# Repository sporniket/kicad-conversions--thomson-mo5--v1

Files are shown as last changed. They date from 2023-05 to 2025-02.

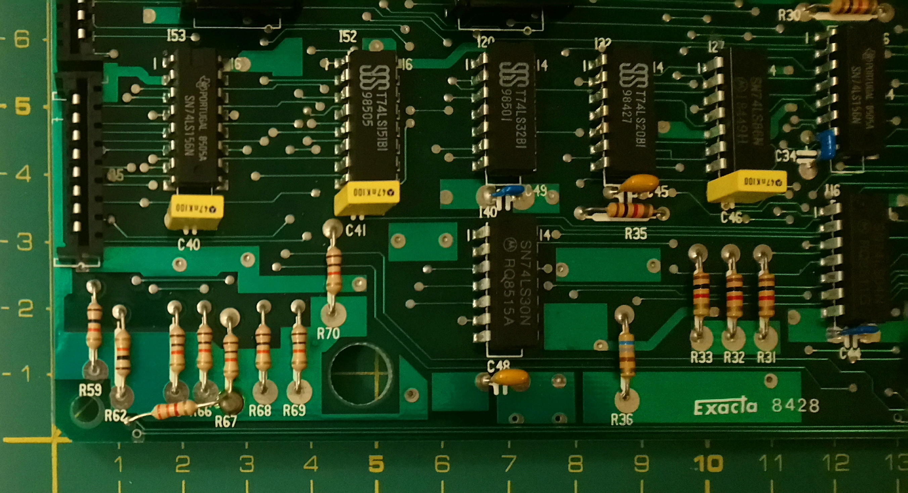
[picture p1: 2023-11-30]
references/motherboard/pictures_top/DSC_1537.JPG

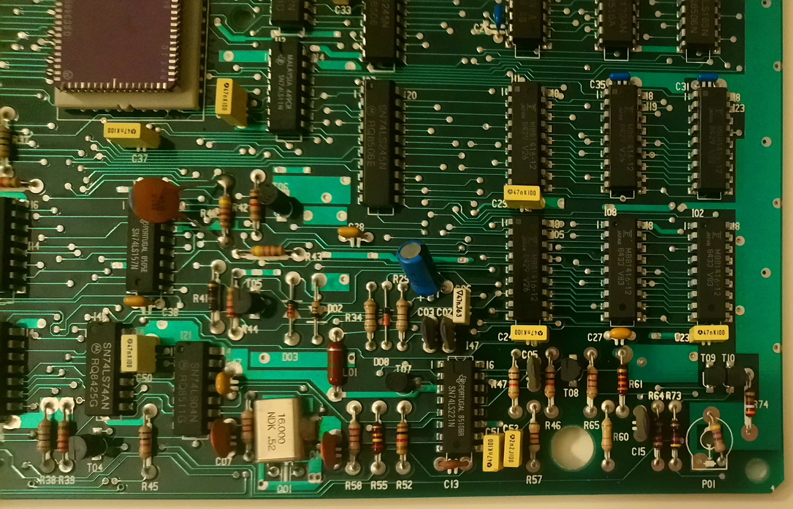
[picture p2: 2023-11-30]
references/motherboard/pictures_top/DSC_1536.JPG

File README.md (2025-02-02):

# Conversion of the Thomson MO5 main board into Kicad

> [WARNING] Please read carefully this note before using this project. It contains important facts.

Content

1. What is **Conversion of the Thomson MO5 main board into Kicad**, and when to use it ?
2. What should you know before using **Conversion of the Thomson MO5 main board into Kicad** ?
3. How to use **Conversion of the Thomson MO5 main board into Kicad** ?
4. Known issues
5. Miscellanous

## 1. What is **Conversion of the Thomson MO5 main board into Kicad**, and when to use it ?

**Conversion of the Thomson MO5 main board into Kicad** is a conversion to Kicad EDA of the schematics of a computer released around 1984 known as the "Thomson MO5".

There are two revisions of the motherboard : 

* The first version, with a Motorola gate array, is maintained on the `main` branch.
* The second version, with an EFCIS gate array, is maintained on the `efcis_gate_array` branch.

### Licence

**Conversion of the Thomson MO5 main board into Kicad** is published under the Creative Commons CC0 license. You can find a copy of the licence there : https://creativecommons.org/publicdomain/zero/1.0/legalcode

You can copy, modify, distribute and perform the work, even for commercial purposes, all without asking permission.

**Conversion of the Thomson MO5 main board into Kicad** is distributed in the hope that it will be useful, but WITHOUT ANY WARRANTY; without even the implied warranty of MERCHANTABILITY or FITNESS FOR A PARTICULAR PURPOSE.

### Release notes

#### v1.0.0-rc2

Because I hastily pushed rc1 and saw small edit just after that : one measurement position, refill the copper pours.

Other than that, same as rc1.

#### v1.0.0-rc1

Fixes found by assembling the motherboard :

* Fixed the power supply : pin 1 of I55 to GND, values of R79 and R80 (shematic is also more easy to understand)
* Fixed the reset circuit : value of C01
* Extended the extension port by 2 mm

For documentation :
* [BOM](README--BOM.md)
* Added measurements to the PCB.

#### v1.0.0-beta-2

* Issue #1 -- Small corrections for beta2
  * Schematic -- fixes unit of L01, 'nH' instead of 'mH'
  * wider lateral chamfers for extension connector, set to 1mm along x and y axis
  * prevent a small copper pour of GND inside the extension connector
  * exclude copper pour around internal mounting holes (front layer)
  * tweak the width of the pads of the extension connector, from 2mm to 1.5mm

* Issue #2 -- Small enhancements for beta2
  * Silkscreen -- add text to render REVISION and ISSUE_DATE
  * enlarge vias for modding cartridge port to get E and R/W 
  * Some additionnal fixes of DRC violations
  * Schematic -- D02 value becomes 'BZX46C12'
  * Reset switch -- ad-hoc footprint to combine regular switch with the original reset button footprint

#### v1.0.0-beta-1

The PCB is finished, ready for testing (mechanical, actual assembly) to spot errors.

#### v1.0.0-alpha-1 to v1.0.0-alpha-6

The whole schematics has been captured, need proofreading. A new alpha is produced regularly after some fixes are commited.

## 2. What should you know before using **Conversion of the Thomson MO5 main board into Kicad** ?

**Conversion of the Thomson MO5 main board into Kicad** is made using Kicad 7.

> Do not use **Conversion of the Thomson MO5 main board into Kicad** if this project is not suitable for your project.

## 3. How to use **Conversion of the Thomson MO5 main board into Kicad** ?

### From sources

To get the latest available work, one must clone the git repository.

	git clone --recurse-submodules https://github.com/sporniket/kicad-conversions--thomson-mo5--v1.git

Then, open the project with Kicad 7.

## 4. Known issues
See the [project issues](https://github.com/sporniket/kicad-conversions--thomson-mo5--v1/issues) page.

## 5. Miscellanous

### Report issues
Use the [project issues](https://github.com/sporniket/kicad-conversions--thomson-mo5--v1/issues) page.

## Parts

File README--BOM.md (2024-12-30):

# Bill of material

> On A4 sized sheets of paper, best printed using landscape format, zooming at most 75%.

## Capacitors

### Non polarized

|Quantity|Designators|Value|Comment|Suggestion|
|---|---|---|---|---|
|5|C02, C03, C05, C15, C60|100pF|Radial, pitch 5,08mm/200mils|Vishay K101K10X7RH5UH5|
|32|C06, C21, C22, C23, C24, C25, C26, C27, C28, C29, C30, C31, C32, C33, C34, C35, C36, C37, C38, C39, C40, C41, C42, C43, C44, C45, C46, C47, C48, C49, C50, C51|47nF|Radial, pitch 5,08mm/200mils|Vishay K473K10X7RF5UH5|
|2|C07, C14|120pF|Radial, pitch 5,08mm/200mils|Vishay K121K10X7RF5UH5|
|7|C08, C09, C10, C11, C16, C17, C19|220nF|Radial, pitch 5,08mm/200mils|Vishay K224K20X7RF5TH5|
|2|C12, C61|6.8nF|Radial, pitch 5,08mm/200mils|Vishay K682K10X7RH5UH5|
|1|C13|1nF|Radial, pitch 5,08mm/200mils|Vishay K102K10X7RH5UH5|
|1|C18|10nF|Radial, pitch 5,08mm/200mils|Vishay K103K15X7RF5UH5|
|1|C52|2.2uF|Radial, pitch 5,08mm/200mils|TDK FG28X5R1E225KRT06|
|1|C59|18pF|Radial, pitch 5,08mm/200mils|Vishay K180J15C0GF5TH5|

### Polarized

Electrolytic capacitors.

|Quantity|Designators|Value|Comment|Suggestion|
|---|---|---|---|---|
|2|C01, C53|100uF|Radial, Pitch 5,08mm/200mils|Wurth Elektronik 860020473008|
|2|C04, C20|4.7uF|Radial, Pitch 5,08mm/200mils|Wurth Elektronik 860020472001|
|2|C54, C57|10uF|Radial, Pitch 5,08mm/200mils|Wurth Elektronik 860020472003 |
|1|C55|470uF|Radial, Diameter 10mm, Pitch 5mm|Wurth Elektronik 860020474014|
|1|C56|1000uF|Radial, Diameter 13mm, Pitch 5mm|Wurth Elektronik 860020475018|

## Diodes

|Quantity|Designators|Value|Comment|Suggestion|
|---|---|---|---|---|
|6|D01, D03, D04, D05, D06, D08|1N4148|Horizontal mount, pitch 500mils|Onsemi/Fairchild 1N4148-T26A|
|1|D02|BZX46C12|Horizontal mount, pitch 500mils|Vishay Semiconductors BZX55C12-TAP|
|1|D07|BYW98-100|Horizontal mount, pitch 700mils ; the body hangs in the air, at least 1cm appart from the PCB|Diodes incorporated 1N5401G-T|

## Inductors

|Quantity|Designators|Value|Comment|Suggestion|
|---|---|---|---|---|
|1|L01|150nH|Coated leaded inductor|Bourns 78FR15M-RC|
|1|L02|350uH|Ferrite core inductor||
|1|L03|15uH|Ferrite core inductor||

## Crystal oscillator

|Quantity|Designators|Value|Comment|Suggestion|
|---|---|---|---|---|
|1|Q01|16MHz|HC49-U format, horizontal mounting|Abracon AB-16.000MHZ-B2|

## Resistors

> Unless stated otherwise, mounting is horizontal with a pitch of 500 mils.

|Quantity|Designators|Value|Comment|Suggestion|
|---|---|---|---|---|
|19|R01, R03, R05, R10, R30, R31, R32, R33, R35, R42, R48, R49, R50, R51, R52, R56, R77, R78, R82|1KΩ||YAGEO MFR-25FTE52-1K|
|4|R02, R04, R06, R41|68Ω||YAGEO MFR-25FTE52-68R|
|2|R07, R36|680Ω||YAGEO MFR-25FTE52-680R|
|2|R08, R71|100KΩ||YAGEO MFR-25FTE52-100K|
|1|R09|220Ω||YAGEO MFR-25FTE52-220R|
|3|R11, R12, R13|3K3Ω||YAGEO MFR-25FTE52-3K3|
|14|R14, R17, R22, R45, R46, R47, R59, R62, R63, R66, R67, R68, R69, R70|10KΩ||YAGEO MFR-25FTE52-10K|
|3|R15, R18, R20|3KΩ||YAGEO MFR-25FTE52-3K|
|7|R16, R19, R21, R39, R44, R54, R58|22KΩ||YAGEO MFR-25FTE52-22K|
|8|R23, R24, R25, R26, R27, R28, R40, R43|4K7Ω||YAGEO MFR-25FTE52-4K7|
|3|R29, R34, R38|100Ω||YAGEO MFR-25FTE52-100R|
|1|R37|75Ω||YAGEO MFR-25FTE52-75R|
|2|R53, R61|33KΩ||YAGEO MFR-25FTE52-33K|
|1|R55|24KΩ||YAGEO MFR-25FTE52-24K|
|1|R57|820Ω||YAGEO MFR-25FTE52-820R|
|1|R60|330KΩ||YAGEO MFR-25FTE52-330K|
|1|R64|180Ω||YAGEO MFR-25FTE52-180R|
|1|R65|2K7Ω||YAGEO MFR-25FTE52-2K7|
|1|R72|39KΩ|Vertical mounting, pitch 200mils|YAGEO MFR-25FTE52-39K|
|1|R73|47Ω||YAGEO MFR-25FTE52-47R|
|1|R74|390Ω||YAGEO MFR-25FTE52-390R|
|2|R75|15KΩ||YAGEO MFR-25FTE52-15K, KOA Speer MF1/4CCT52R1502F|
|1|R76|3K9Ω||YAGEO MFR-25FTE52-3K9|
|1|R79|1K5Ω||YAGEO MFR-25FTE52-1K5|
|1|R80|27KΩ||YAGEO MFR-25FTE52-27K|
|2|R81, R83|330Ω||YAGEO MFR-25FTE52-330R|

## Transistors

|Quantity|Designators|Value|Comment|Suggestion|
|---|---|---|---|---|
|8|T01, T02, T03, T06, T07, T09, T10, T11|BC547B|TO-92|Diotec Semiconductor BC547B|
|2|T04, T08|BC557B|TO-92|Diotec Semiconductor BC557B|
|1|T05|BC337-40|TO-92|Diotec Semiconductor BC337-40|
|1|T12|BDX54|TO-220-3|STMicroelectronics BDX54C|

## Integrated Circuits

|Quantity|Designators|Value|Comment|Suggestion Socket|Suggestion IC|Datasheet|
|---|---|---|---|---|---|---|
|1|I01|MC6809EP|DIP 40 W15.24mm|Adam Tech ICS-640-T||https://ia601601.us.archive.org/13/items/bitsavers_motorolada_3224333/6809.pdf|
|6|I02, I05, I08, I11, I19, I23|TMS4416 – 16k×4bits DRAM|DIP 18 W7.62mm|Adam Tech ICS-318-T||https://raw.githubusercontent.com/sporniket/kicad-symbols-generated/main/reference-materials/commons/memory/tms4416.pdf|
|1|I03|HM7603 32×8 PROM|DIP 16 W7.62mm|Adam Tech ICS-316-T||https://raw.githubusercontent.com/sporniket/kicad-symbols-generated/main/reference-materials/commons/eprom/hm7603.pdf|
|1|I04|M27128A 16k×8 EPROM|DIP 28 W15.24mm|Adam Tech ICS-628-T||https://pdf.datasheetcatalog.com/datasheet_pdf/sgs-thomson-microelectronics/27128.pdf|
|2|I06, I10|74LS173 Registre D 4 bits|DIP 16 W7.62mm|Adam Tech ICS-316-T||https://www.ti.com/lit/ds/symlink/sn54ls173a.pdf|
|2|I07, I17|74LS245 – Bus transceiver|DIP 20 W7.62mm|Adam Tech ICS-320-T||https://www.ti.com/lit/ds/symlink/sn54ls245-sp.pdf|
|1|I09|74LS32 – 4× 2-input OR gates|DIP 14 W7.62mm|Adam Tech ICS-314-T||https://www.ti.com/lit/ds/symlink/sn74ls32.pdf|
|1|I12|74LS11 – 3×3 inputs AND gates|DIP 14 W7.62mm|Adam Tech ICS-314-T||https://www.ti.com/lit/ds/symlink/sn54ls11.pdf|
|1|I14|74LS156 2×2:4 decoder/demultiplexer|DIP 16 W7.62mm|Adam Tech ICS-316-T||https://www.ti.com/lit/ds/symlink/sn74ls156.pdf|
|2|I16, I21|74LS04 Sextuple inverseur|DIP 14 W7.62mm|Adam Tech ICS-314-T||https://www.ti.com/lit/ds/symlink/sn74ls04.pdf|
|1|I18|74LS165 Sérialiseur 8:1|DIP 16 W7.62mm|Adam Tech ICS-316-T||https://www.ti.com/lit/ds/symlink/sn54ls165a-sp.pdf|
|1|I20|74LS32 4×2 inputs OR gates|DIP 14 W7.62mm|Adam Tech ICS-314-T||https://www.ti.com/lit/ds/symlink/sn74ls32.pdf|
|1|I25|74LS126 Quadruple tampon de bus|DIP 14 W7.62mm|Adam Tech ICS-314-T||https://www.ti.com/lit/ds/symlink/sn54ls125a.pdf|
|1|I27|DM7486N 4×2 inputs XOR gates|DIP 14 W7.62mm|Adam Tech ICS-314-T||https://www.ti.com/lit/ds/symlink/sn54s86.pdf|
|1|I29|Gate array Motorola MC1300|Staggered PLCC68 with keyhole||||
|1|I32|74X20 2×4 inputs NAND gates|DIP 14 W7.62mm|Adam Tech ICS-314-T||https://www.ti.com/lit/ds/symlink/sn74ls20.pdf|
|1|I40|74LS30 8 inputs NAND gate|DIP 14 W7.62mm|Adam Tech ICS-314-T||https://www.ti.com/lit/ds/symlink/sn5430.pdf|
|1|I45|74LS74 Double Flip-Flop 'D'|DIP 14 W7.62mm|Adam Tech ICS-314-T||https://www.ti.com/lit/ds/sdls119/sdls119.pdf|
|1|I46|74LS157 4×2:1 Multiplexeur|DIP 16 W7.62mm|Adam Tech ICS-316-T||https://www.ti.com/lit/ds/symlink/sn54157.pdf|
|1|I47|74LS211 Double multi-vibrateur monostable|DIP 16 W7.62mm|Adam Tech ICS-316-T||https://www.ti.com/lit/ds/symlink/sn74221.pdf|
|1|I48|MC6821 Peripheral Interface Adapter|DIP 40 W15.24mm|Adam Tech ICS-640-T||https://d148k72crfmm2d.cloudfront.net/wp-content/uploads/2017/02/MC6821P.pdf|
|1|I52|74LS151 MULTIPLEXER|DIP 16 W7.62mm|Adam Tech ICS-316-T||https://www.ti.com/lit/ds/symlink/sn74ls151.pdf|
|1|I53|74LS156 DEMULTIPLEXER|DIP 16 W7.62mm|Adam Tech ICS-316-T||https://www.ti.com/lit/ds/symlink/sn74ls156.pdf|
|1|I54|L78L05 TO92|TO-92||STMicroelectronics L78L05ABZ|http://www.st.com/content/ccc/resource/technical/document/datasheet/15/55/e5/aa/23/5b/43/fd/CD00000446.pdf/files/CD00000446.pdf/jcr:content/translations/en.CD0000044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|
|1|I55|LM311N Comparateur différentiel|DIP 8 W7.62mm|Adam Tech ICS-308-T||https://www.ti.com/lit/ds/symlink/lm211.pdf|

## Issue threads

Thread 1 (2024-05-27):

Small corrections for beta2

sporniket, 2024-05-27:
# Schematic

* [x] While working on the BOM, I noticed that L01 is valued to 150mH. Original schematics stated "150" (no unit) and the other inductance (350uH and 15uH) are way bigger, so it should be 150nH I guess.

# PCB

Following production of first batch, some details to change

* [x] lateral chamfer of extension connector should be around 0.8~1.5 mm wide (now it is around a unnoticeable 0.2 mm)
* [x] contact width of extension connector should be narrower (around 1mm of spacing)
* [x] there is a small copper pour on the left of the extension connector, to be removed
* [x] exclude copper pour on topside of internal monting holes actually used for mounting

sporniket, 2024-06-02:
Done

Closed 2024-06-02.

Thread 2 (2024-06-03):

Small enhancements for beta2

sporniket, 2024-06-03:
# Schematic

* [x] D02 : value should be `BZX46C12` instead of `BZX46C`

# PCB

* [x] Silkscreen : add text to render `${ISSUE_DATE}` and `${REVISION}`
* [x] Enlarge vias for modding cartridge port to get E and R/W
* [x] Reset switch : ad-hoc footprint to combine regular switch with the original reset button footprint

sporniket, 2024-11-11:
All is done with fa9e29d40a1647247d43c02f81874838f9e4ce9b

Closed 2024-11-11.

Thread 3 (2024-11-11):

Fix power supply circuit

sporniket, 2024-11-11:
* [ ] LM311 pin 1 (emit out) must be grounded
* [ ] R79 value is 7k5

sporniket, 2024-11-11:
Done with 3cb61d4

sporniket, 2024-11-25:
Done with 4092a74

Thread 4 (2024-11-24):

Fix reset circuit

sporniket, 2024-11-24:
* [ ] C01 is 1uF

Closed 2024-11-25.

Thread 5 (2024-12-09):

extends the extension port by 2mm

sporniket, 2024-12-09:
After actual mesure of an original motherboard, the extension port is 0.5mm short, and that may prevent an extension to be plugged correctly. For good measure, I will extends the port by 2mm

* extends the length depth of the extension port by 2mm
* move the contacts by 1 mm
* update the measurements

Closed 2024-12-30.

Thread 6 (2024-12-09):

adapt R22, R17 and R14 to get video voltage levels compatible with modern LCD

sporniket, 2024-12-09:
LTSpice would give around 2V2 as full voltage at the emitter of  T01, T02, and T03, and thus would require 1k4 value for R22, R17 and R14 to get 0.7v.

* Measure the voltage (on the green and blue) to check actual full value
* Depending on the result, experiments with 1k4 or adapt to the result.

Leave a note on the schematic.

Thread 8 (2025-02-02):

[EFCIS GA] Adapt the schematics to the different gate array

sporniket, 2025-02-02:
A significant number of signals have moved (change of pinout)

to find : 
* new pin#43 `/FIPT`
* new pin#68 `/CS`

TODO :
* [ ] Schematics (with checks)
* [ ] BOM (PLCC socket)

sporniket, 2025-02-08:
Schematics done with 0f8ba69

sporniket, 2025-02-08:
Pin 57 done with 12dd2fb

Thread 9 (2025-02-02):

[EFCIS GA] Add SIPP ram modules I100, I101 and I102

sporniket, 2025-02-02:
The motherboard can have either DIP RAM chips, or custom SIPP RAM modules carrying a pair of those RAM chips

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

> See https://forum.system-cfg.com/viewtopic.php?p=264548#p264548

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

## TODO

* [x] custom symbol
* [ ] custom footprint (variation from connector 01x21
* [x] schematic

sporniket, 2025-02-15:
Duplicated by #15

Won't do the custom footprint

sporniket, 2025-02-15:
done with e48dc0e

Closed 2025-02-15.

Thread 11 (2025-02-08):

[ga efcis][schematics] Rewire I16 and I21

sporniket, 2025-02-08:
I16 inverts following signals, ordered by pin number : 
* `A5`
* `A4`
* `A3`
* `A12`
* `A11`
* `A2`

I21 inverts the following signals, ordered by pin number : 
* `/SYCL`
* `A14`
* `/DATA_VALID`
* `/POINT` (pin 13)

I21, pin 8 to 11 are inchanged

Closed 2025-02-08.

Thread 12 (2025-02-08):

[ga efcis] pin 36 not connected and wrong symbol

sporniket, 2025-02-08:

sporniket, 2025-02-08:
done with 793025b0bab2843e245d1910f11ed4448a056c71

Closed 2025-02-08.

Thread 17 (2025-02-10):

[ga efcis] Thermal switch F01 MAY be bypassed with S05 jumper wire

sporniket, 2025-02-10:
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

sporniket, 2025-04-19:
Done while reworking the power circuit for #18

Closed 2025-04-19.

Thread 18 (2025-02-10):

[ga efcis] new power circuitry

sporniket, 2025-02-10:
## Noteworthy

* Thyristor SCR D10, TO-220 package, TYP212
* I54, TO-220, MC 7812 CT

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

sporniket, 2025-04-19:
Done with :

* c85313d69e5f10ea66175d7f7c0253715d5aac23
* 0bf2221cea57962dbfd663cf76e2bca68646ce13
* 975c99d22b0e1620410cc5ed482272a03656f564
* 0cdaef19b9e5bfef5f940ec35f1ba37acd803c90
* 4329a901a4c10c3e0ce1444747432a3804ae77a6
* 4934c647e0ac2305c406a4991f46d54ec7026f92
* b3459a1cbccf4d489b01a8ed30c22d26c9b2c7ae

Closed 2025-04-19.

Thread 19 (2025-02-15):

[ga motorola][bug] Schematics of cartridge port

sporniket, 2025-02-15:
The orientation of the symbol is wrong

* mirrors the whole setup against the Y axis (the a part is on the right side, the first pin to the north side)
* the mention "rangée a vers le sud" MUST be changed to "rangée a vers le nord" (check this point)

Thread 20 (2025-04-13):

[efcis] investigate missing capacitors (footprints on PCB, not found on schematics)

sporniket, 2025-04-13:
C62, C63, C65, C69, C70, C80

sporniket, 2025-04-14:
C69

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

sporniket, 2025-04-14:
C62 and C63

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

sporniket, 2025-04-19:
C65 : filters R86 -- T05.1

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

sporniket, 2025-04-19:
C80 : filters I06.1 ?

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

Closed 2025-04-19.

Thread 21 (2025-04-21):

[efcis] missing C58

sporniket, 2025-04-21:
Filters `Couleur_tour.pt`

47nF, can be seen in schematics

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

Closed 2025-04-21.

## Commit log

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2023-05-12 organisation prospective des sous-schémas
    [UC-50-001.kicad_pcb, UC-50-001.kicad_sch, subsheet_100.kicad_sch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]
2023-05-12 place les principaux circuits -- il manque le symbole pour le PIA MC6821
    [UC-50-001.kicad_sch, subsheet_101.kicad_sch, subsheet_102.kicad_sch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]
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2023-05-12 done subsheet 100 : CPU
    [UC-50-001.kicad_sch, subsheet_100.kicad_sch, subsheet_103.kicad_sch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]
2023-05-12 ajuste position des signaux globaux
    [subsheet_100.kicad_sch]
2023-05-13 cpu : sépare le circuit reset du pull-up de la broche 34
    [UC-50-001.kicad_sch, subsheet_100.kicad_sch]
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2023-05-13 information schéma, commence le gate array I29
    [UC-50-001.kicad_sch, subsheet_100.kicad_sch, subsheet_101.kicad_sch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]
2023-05-13 fix data and address bus label
    [subsheet_100.kicad_sch]
2023-05-13 done I29, fixed address/databus mapping
    [UC-50-001.kicad_sch, subsheet_100.kicad_sch, subsheet_101.kicad_sch]
2023-05-13 bouge les composants de référence vers la feuille du pia
    [UC-50-001.kicad_sch, subsheet_101.kicad_sch, subsheet_103.kicad_sch]
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2023-05-13 fin provisoire du PIA
    [UC-50-001.kicad_sch, subsheet_103.kicad_sch]
2023-05-14 RAM : drams, transceiver couleur et point
    [UC-50-001.kicad_sch, subsheet_102.kicad_sch, subsheet_103.kicad_sch]
2023-05-14 RAM : temporairement fini
    [UC-50-001.kicad_sch, subsheet_102.kicad_sch, subsheet_103.kicad_sch]
2023-05-14 provisionne une feuille pour le système d'horloges
    [UC-50-001.kicad_sch, subsheet_107.kicad_sch]
2023-05-14 rename GA_E/GA_Q/~{GA_E} into E/Q/~{E}
    [UC-50-001.kicad_sch, subsheet_100.kicad_sch, subsheet_101.kicad_sch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]
2023-05-14 Port LEP : report des voltages
    [subsheet_103.kicad_sch]
2023-05-14 commence le circuit d'alimentation
    [UC-50-001.kicad_sch, subsheet_102.kicad_sch, subsheet_106.kicad_sch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]
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2023-05-14 correction PIA : bus addresse, réarrangement du port clavier A
    [subsheet_103.kicad_sch]
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2023-05-15 continue l'horlogerie : 16 MHz
    [UC-50-001.kicad_sch, subsheet_106.kicad_sch]
2023-05-16 horloges : generation CRTV, CLTV
    [UC-50-001.kicad_sch, subsheet_106.kicad_sch]
2023-05-17 horloges : stylo optique
    [UC-50-001.kicad_sch, subsheet_106.kicad_sch, subsheet_107.kicad_sch]
2023-05-18 fix 74x32 symbol ; better visualization from light pen pin 4 to light pen interrupt signal
    [subsheet_102.kicad_sch, subsheet_103.kicad_sch]
2023-05-18 declare color data bus et point data bus
    [subsheet_102.kicad_sch]
2023-05-18 cadencement -- arrangement visuel
    [UC-50-001.kicad_sch, subsheet_103.kicad_sch, subsheet_106.kicad_sch]
2023-05-18 sépare visuellement les portes de I09 et I12
    [UC-50-001.kicad_sch, subsheet_102.kicad_sch]
2023-05-18 Point de test 1
    [UC-50-001.kicad_sch, subsheet_107.kicad_sch]
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2023-05-18 Nommage de signaux d'après documentations techniques
    [UC-50-001.kicad_sch, subsheet_102.kicad_sch, subsheet_103.kicad_sch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]
2023-05-19 prepare feuille circuit video
    [UC-50-001.kicad_sch, subsheet_105.kicad_sch]
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2023-05-19 retravaille les ports LEP et crayon optique pour correspondre visuellement (suppression de renversements)
    [UC-50-001.kicad_sch, subsheet_100.kicad_sch, subsheet_101.kicad_sch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]
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2023-05-21 continue le circuit vidéo
    [UC-50-001.kicad_sch, subsheet_105.kicad_sch]
2023-05-21 bouge I21 vers la page du processeur
    [UC-50-001.kicad_sch, subsheet_100.kicad_sch, subsheet_106.kicad_sch]
2023-05-21 rearrange la feuille de cadencement
    [UC-50-001.kicad_sch, subsheet_100.kicad_sch, subsheet_101.kicad_sch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]
2023-05-24 ports d'extension et cartouche
    [UC-50-001.kicad_sch, subsheet_101.kicad_sch, subsheet_103.kicad_sch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]
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2023-05-24 fini eprom, réarrange la feuille, version alpha
    [UC-50-001.kicad_sch, subsheet_100.kicad_sch, subsheet_101.kicad_sch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]
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2023-06-01 forme extérieure de la carte
    [UC-50-001.kicad_pcb, subsheet_103.kicad_sch]
2023-06-24 fixes DRC : duplicate, designators with '?'
    [UC-50-001.kicad_sch, subsheet_100.kicad_sch, subsheet_101.kicad_sch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]
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2023-07-04 schematic : mounting holes
    [UC-50-001.kicad_sch, subsheet_100.kicad_sch, subsheet_101.kicad_sch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]
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2023-07-07 created cartridge footprint and associated with symbol in schematics
    [UC-50-001.kicad_sch, subsheet_104.kicad_sch]
2023-07-07 associate extension ports with their footprints
    [UC-50-001.kicad_sch, subsheet_104.kicad_sch]
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2023-07-08 associate footprint for D02
    [UC-50-001.kicad_sch, subsheet_106.kicad_sch]
2023-08-06 Added footprint : Thomson MO-TO gate array a PLCC68 socket, with staggered pins and key hole
    [UC-50-001.kicad_sch, subsheet_101.kicad_sch]
2023-08-06 fixed thomson extension port backside : pin 1 is named '+12V', not 'ZW02'
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2023-11-04 created and assigned footprints : keyboard and video connectors ; standard barrel-jack ; 6mm standard push button ; trimpot
    [subsheet_100.kicad_sch, subsheet_103.kicad_sch, subsheet_105.kicad_sch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]
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2023-11-04 fixed : S01 footprint
    [subsheet_100.kicad_sch]
2023-11-04 placement : Cpu, gate array, I16, I21, Q01 and passives
    [subsheet_100.kicad_sch]
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2023-11-04 added missing R35, R59, R62, R63, R66~R70
    [subsheet_103.kicad_sch, subsheet_108.kicad_sch]
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2023-11-18 pcb session 2023-11-18T07:44:34+01:00 : changed transistor symbols to swap pins ; there is something wrong with the gate array, even 180° rotation does not fix
    [subsheet_105.kicad_sch, subsheet_106.kicad_sch]
2023-11-18 pcb session 2023-11-18T08:10:40+01:00 : Gate array problem solved, it has to be put on the bottom side
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2023-12-01 pcb session 2023-12-01T09:19:40+01:00 -- fixed T11 connexions and BC 547 symbols
    [subsheet_103.kicad_sch]
2023-12-01 pcb session 2023-12-01T20:37:50+01:00 -- fix transistor symbols, trace south-west quadrant
    [subsheet_106.kicad_sch]
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2024-03-10 Fixes R20, R21, R22
    [subsheet_105.kicad_sch]
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2024-03-11 Change T12 symbol (pin assigment, EBC to BCE) and footprint (TO-92 inline vertical to TO-220-3 vertical)
    [subsheet_107.kicad_sch]
2024-03-17 fixed : add thermal switch between +15V and T12, add heatsink
    [subsheet_107.kicad_sch]
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2024-03-17 adjust the footprint of the heatsink, and the voltage source of I55
    [subsheet_107.kicad_sch]
2024-03-20 fixed C55 connections in schematics to match traces, fixed power symbols names on schematics, and reassign correct nets instead of '+15V'
    [subsheet_107.kicad_sch]
2024-03-20 finished PSU wiring ; fixed C53, HS1 connected to T12#2, trace width
    [subsheet_107.kicad_sch]
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2024-03-23 pcb session 2024-03-23T11:56:01+01:00 -- renumbered shield pin as 'SH'
    [subsheet_103.kicad_sch]
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2024-03-24 pcb session 2024-03-24T08:04:18+01:00 -- routing, I20[12,13] to be left unwired
    [subsheet_108.kicad_sch]
2024-03-28 rework of connectors B04/B05 : footprint, direction on PCB, effect on schematic
    [subsheet_103.kicad_sch]
2024-03-28 rework of connector B03 : footprint, direction on PCB
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2024-03-28 pcb session 2024-03-28T23:30:18+01:00 : I03 completed, color circuit corrected
    [subsheet_105.kicad_sch]
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2024-03-30 pcb session 2024-03-30T07:45:55+01:00 -- net I11-B, fixed net couleur_tour.rt
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2024-03-31 note on the schematic about pin 43 of I29
    [subsheet_101.kicad_sch]
2024-03-31 note on the schematic about pin 64 of I29
    [subsheet_101.kicad_sch]
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2024-04-07 pcb session 2024-04-07T07:45:23+02:00 -- done GND + missing wire R38-T04#3
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2024-04-07 pcb session 2024-04-07T11:09:01+02:00 -- some DRC fixes : missing connection, one via dimensions
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2024-04-14 Fix directions about moding the cartridge port : fixed E and R/*W wiring
    [subsheet_104.kicad_sch]
2024-04-14 Fix directions about moding the cartridge port : fixed footprint on pcb
2024-04-14 pcb session 2024-04-14T16:16:16+02:00 -- fix all positionning DRC violations except HS1/T12, start copper pours
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2024-04-20 pcb session 2024-04-20T08:46:59+02:00 -- copper pours +5V bottom -- reworked to be more faithfull to original shapes
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2024-04-20 pcb session 2024-04-20T15:33:52+02:00 -- copper pours +5V up done -- fixed I29#52
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2024-06-02 Issue #1 -- Small corrections for beta2 -- fix unit of L01, 'nH' instead of 'mH'
    [subsheet_106.kicad_sch]
2024-06-02 Issue #1 -- Small corrections for beta2 -- wider lateral chamfers for extension connector, set to 1mm along x and y axis
2024-06-02 Issue #1 -- Small corrections for beta2 -- prevent a small copper pour of GND inside the extension connector
2024-06-02 Issue #1 -- Small corrections for beta2 -- exclude copper pour around internal mounting holes (front layer)
2024-06-02 Issue #1 -- Small corrections for beta2 -- tweak the width of the pads of the extension connector, from 2mm to 1.5mm
    [subsheet_104.kicad_sch]
2024-06-07 Issue #2 -- Small enhancements for beta2 -- Silkscreen -- add text to render REVISION and ISSUE_DATE
2024-06-07 Issue #2 -- Small enhancements for beta2 -- Schematic -- D02 value becomes 'BZX46C12'
    [subsheet_106.kicad_sch]
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2024-06-09 Issue #2 -- Small enhancements for beta2 -- Reset switch -- ad-hoc footprint to combine regular switch with the original reset button footprint
    [subsheet_100.kicad_sch]
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2024-07-01 fix value of T11 (removed spaces)
    [subsheet_103.kicad_sch]
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2024-07-02 BOM -- fixed comment for I54
2024-07-31 rework pcb edge for measurements
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2024-11-11 Issue #3 -- Tie I55.1 to GND
    [subsheet_107.kicad_sch]
2024-11-11 Issue #3 -- fix R79 value to 7K5
    [subsheet_107.kicad_sch]
2024-11-17 Reworked power supply circuitry : resistors value, schematic layout
    [subsheet_107.kicad_sch]
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2024-11-25 Resolves #4 : Fix reset circuit
    [subsheet_100.kicad_sch]
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2024-12-30 Resolves #5 : extends the extension port by 2mm
2024-12-30 BOM -- forgot to fix R79 and R80
2024-12-30 prepare release : issue date
    [UC-50-001.kicad_sch, subsheet_100.kicad_sch, subsheet_101.kicad_sch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]
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2025-02-01 #7 [bad value] R54 and R58 are 2K2, not 22K -- schematic
    [subsheet_100.kicad_sch]
